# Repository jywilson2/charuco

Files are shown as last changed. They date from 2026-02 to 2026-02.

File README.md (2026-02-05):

# Parametric 3D-Printable ChArUco Calibration Target

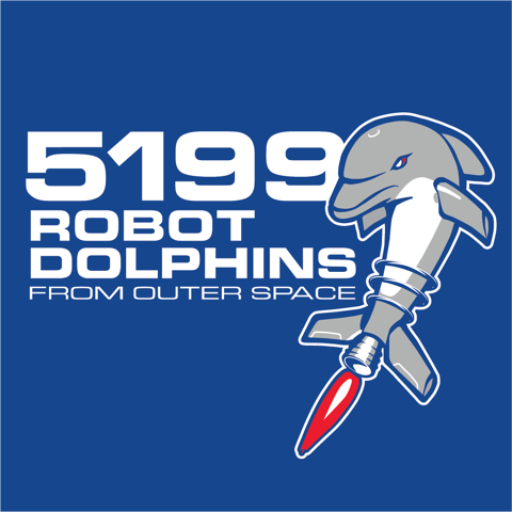
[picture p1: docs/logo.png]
Robot Dolphins from Outer Space Logo


**Developed by Robot Dolphins from Outer Space: Team 5199 & Gemini Pro**

A robust OpenSCAD toolkit for generating large-scale ChArUco calibration boards that can be split and 3D printed on standard-sized beds. This project features precision multi-material slicing support and modular assembly options, making it easy to create professional-grade computer vision calibration targets without a large-format printer.

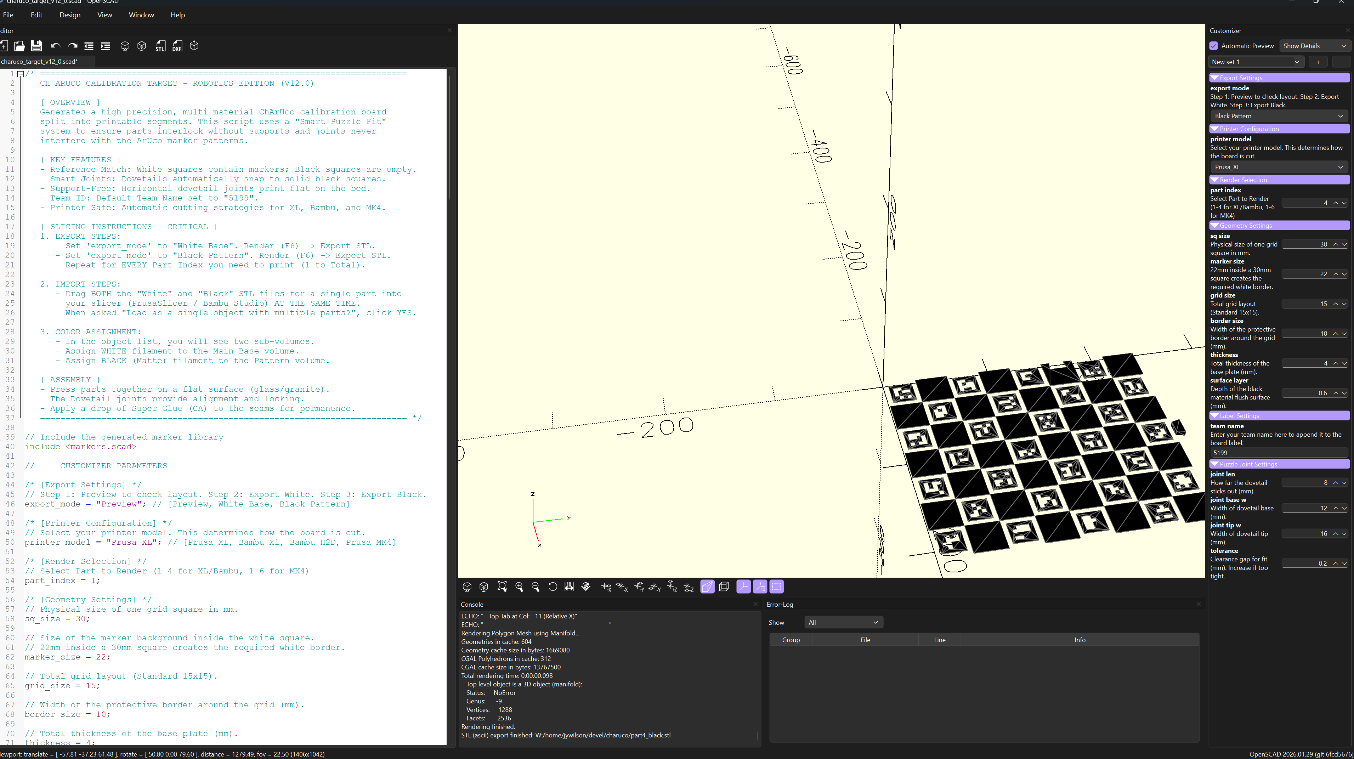
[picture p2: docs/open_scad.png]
OpenSCAD Generator Preview

*Figure 1: The parametric model rendered in OpenSCAD, showing the modular split and alignment features.*

## Pre-Generated Files

For convenience, we have provided ready-to-print files for a standard **15x15 Grid** configuration:

* **STL Models (`stl/`):** Contains exported "White Base" and "Black Pattern" files pre-configured for:
    * Prusa XL
    * Bambu Labs X1E
* **Slicer Projects (`slicer/`):** Contains pre-configured project files (with multi-material settings applied) for:
    * **Prusa Slicer** (for Prusa XL)
    * **Bambu Studio** (for Bambu Labs X1E)

## Key Features

* **Auto-Splitting:** Automatically slices large targets (e.g., 15x15 grids) into printable sections compatible with standard build volumes like the Prusa XL, Bambu X1, and Prusa MK4.
* **Modular Assembly:** Choose between two robust connection styles:
    * **Smart Dovetails:** Precision puzzle-fit with anchored geometry for a flat, glue-assembled board.
    * **Joiner Plates:** Reinforced screw-fastened connections using printed plates and standard M3/wood screws. **(⚠️ Note: This connection style is currently in development and untested.)**
* **Multi-Material Ready:** Generates separate "White Base" and "Black Pattern" STL files with anchored geometry, ensuring perfect boolean unions in slicers.
* **Robust Geometry:** Includes reinforcement bosses for screw holes and "top-open" dovetail slots to ensure easy assembly and structural integrity.
* **Python Integration:** Includes a helper script to generate standard ArUco dictionary patterns (`markers.scad`).

## Usage Summary

1.  **Generate Markers:** Run the included Python script to generate the ArUco marker library:
    ```bash
    python generate_library.py
    ```
2.  **Configure:** Open the `.scad` file in OpenSCAD and select your **Printer Model** and **Connection Type** in the Customizer.
    * *Note: Extensive usage information, advanced configuration options, and logic explanations are provided as inline comments within the SCAD source file.*
3.  **Export:** Select the **Part Index** you wish to print, then export the `White Base` and `Black Pattern` files separately.
4.  **Print:** Import both files into your slicer as a "Multi-Part Object" to preserve alignment and assign filament colors.

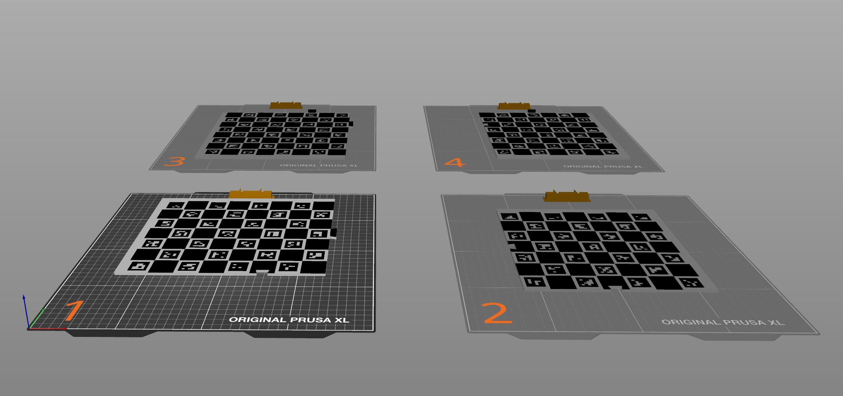
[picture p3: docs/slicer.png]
Slicer Multi-Material Setup

*Figure 2: The generated parts imported into the slicer as a single multi-material object, ready for printing.*

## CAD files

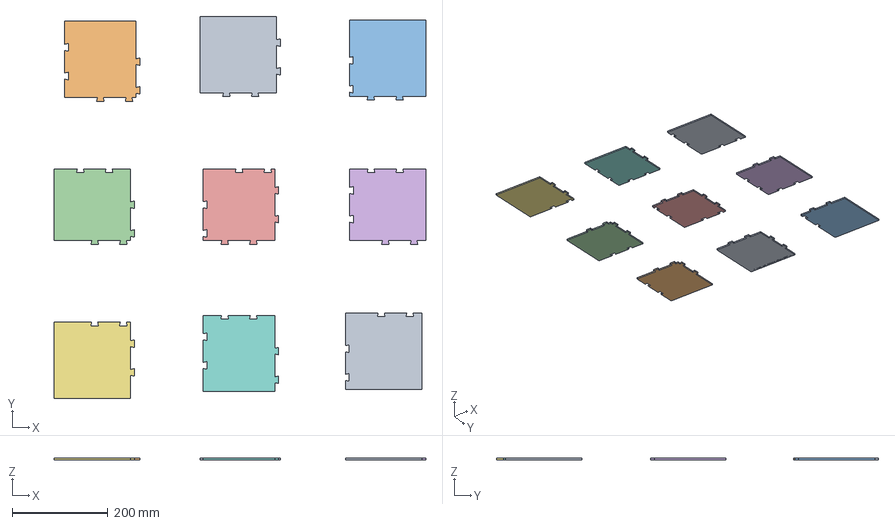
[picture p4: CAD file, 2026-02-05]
slicer/bambu_labs_x1e_15x15.3mf
778.4 x 799.9 x 4.00 mm
part_1_black_short_dove_tail
part_2_black_short_dove_tail
part_3_black_short_dove_tail
part_4_black
part_5_black
part_6_black
part_7_black
part_8_black
part_9_black

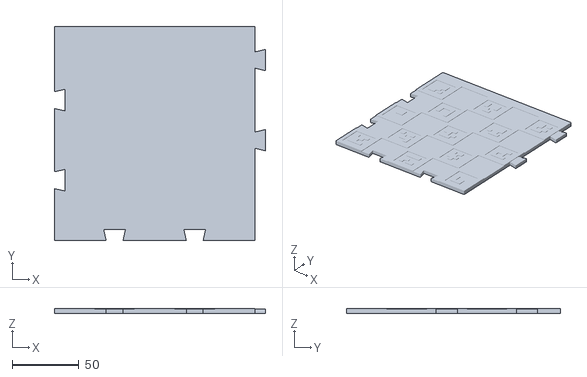
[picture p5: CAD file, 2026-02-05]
stl/bambu_labs_x1e/part_8_white.stl
158.0 x 160.0 x 4.00

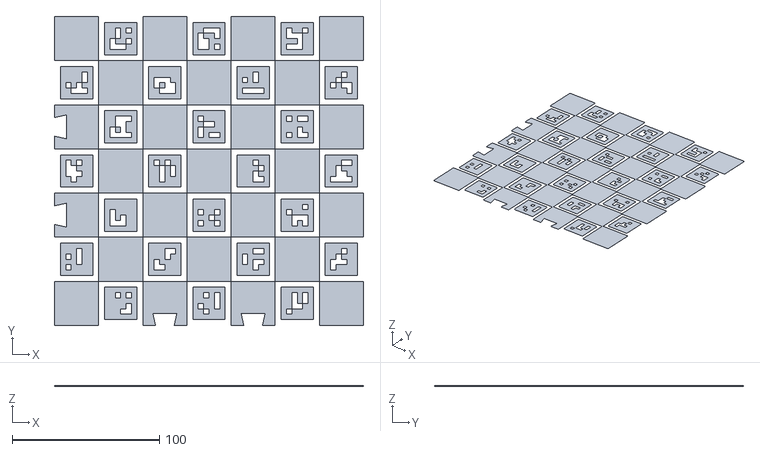
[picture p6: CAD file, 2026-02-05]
stl/prusa_xl/part2_black.stl
210.0 x 210.0 x 0.6

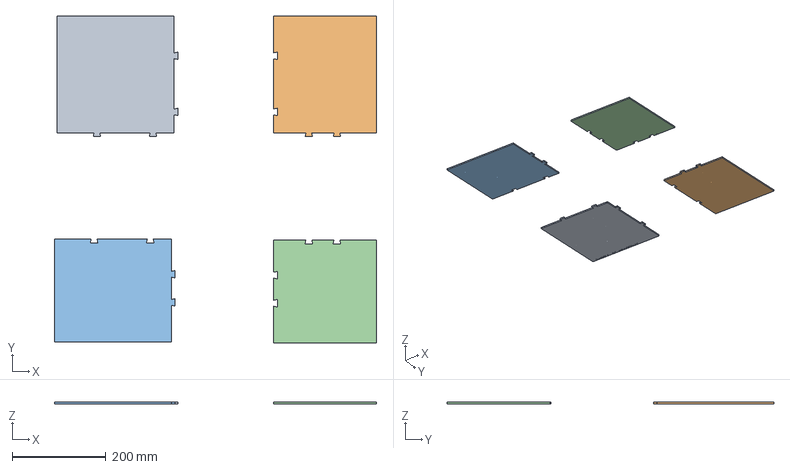
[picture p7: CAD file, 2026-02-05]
slicer/prusa_xl_15x15.3mf
689.0 x 699.1 x 4.00 mm
part3_black
part4_black
part1_black
part2_black

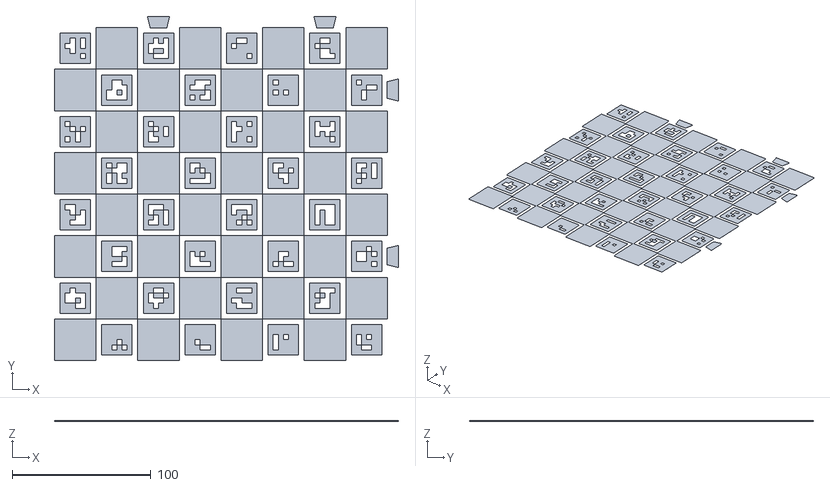
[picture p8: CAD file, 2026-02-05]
stl/prusa_xl/part3_black.stl
248.0 x 248.0 x 0.6

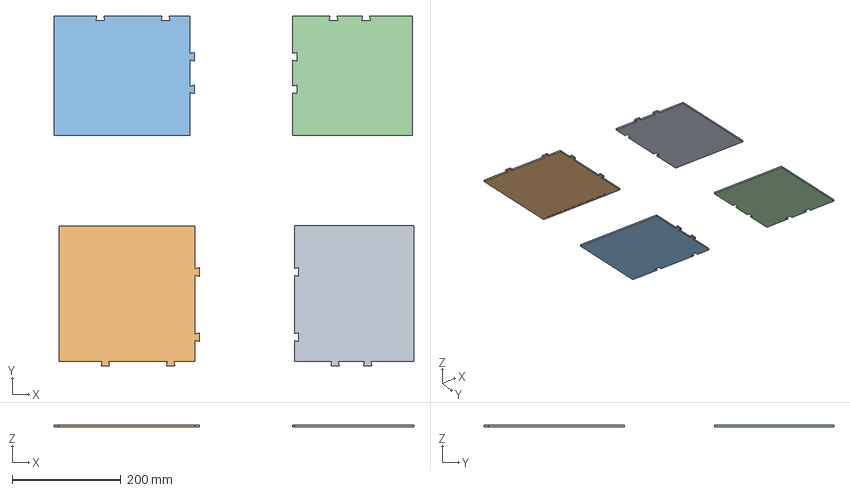
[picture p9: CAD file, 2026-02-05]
slicer/bambu_labs_h2d_15x15.3mf
661.9 x 644.0 x 4.00 mm
part4_black
part3_black
part1_black
part2_black

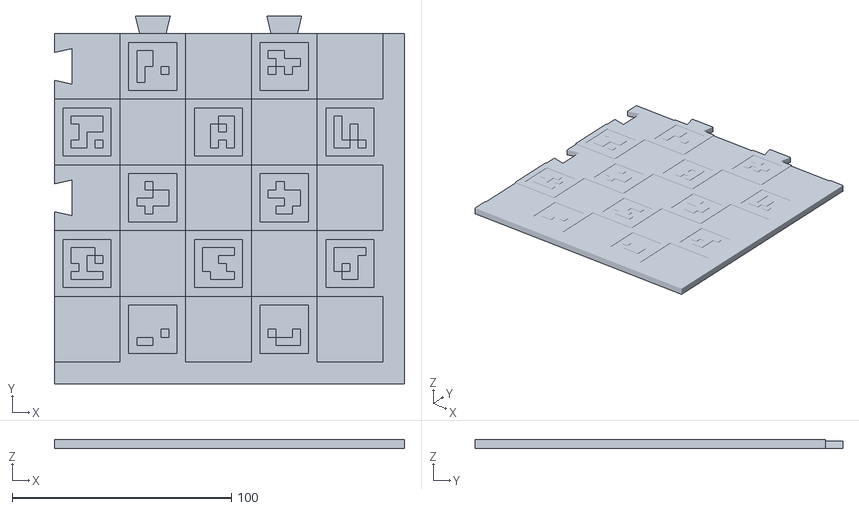
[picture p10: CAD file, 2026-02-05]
stl/bambu_labs_x1e/part_3_white.stl
160.0 x 168.0 x 4.00

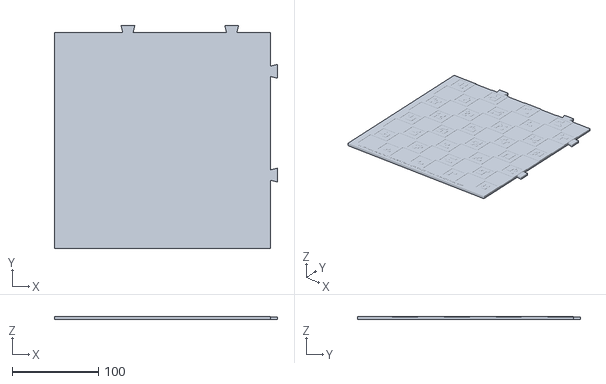
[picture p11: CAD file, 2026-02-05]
stl/prusa_xl/part3_white.stl
258.0 x 258.0 x 4.00

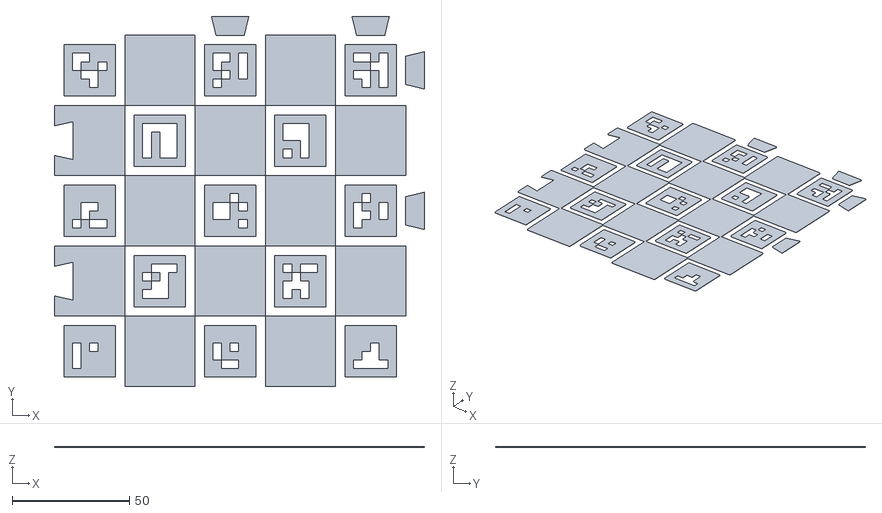
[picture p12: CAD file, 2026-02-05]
stl/bambu_labs_x1e/part_2_black.stl
158.0 x 158.0 x 0.6

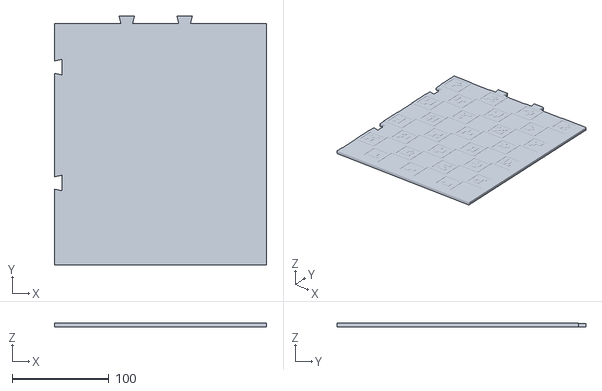
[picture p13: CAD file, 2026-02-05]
stl/prusa_xl/part4_white.stl
220.0 x 258.0 x 4.00

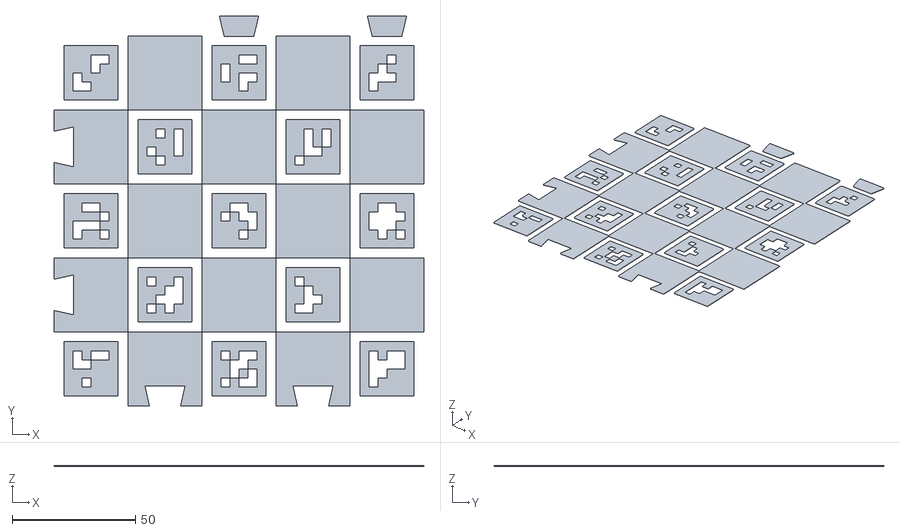
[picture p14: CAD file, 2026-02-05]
stl/bambu_labs_x1e/part_6_black.stl
150.0 x 158.0 x 0.6

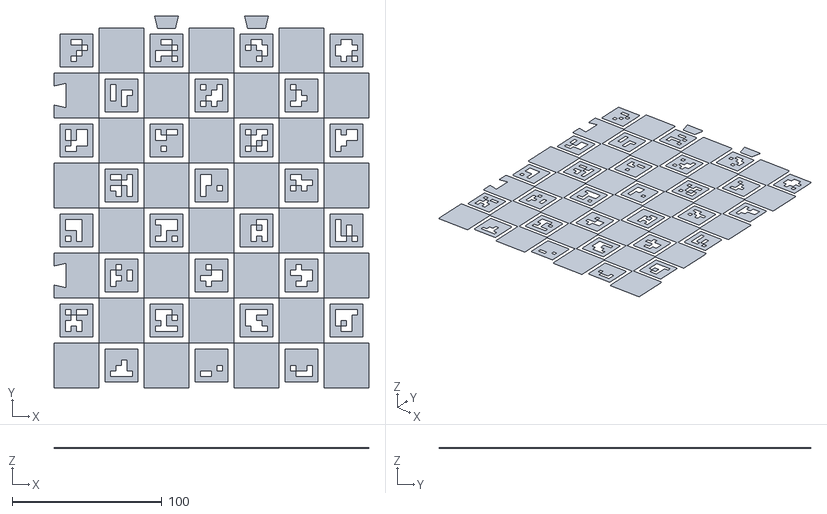
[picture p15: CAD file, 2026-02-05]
stl/prusa_xl/part4_black.stl
210.0 x 248.0 x 0.6

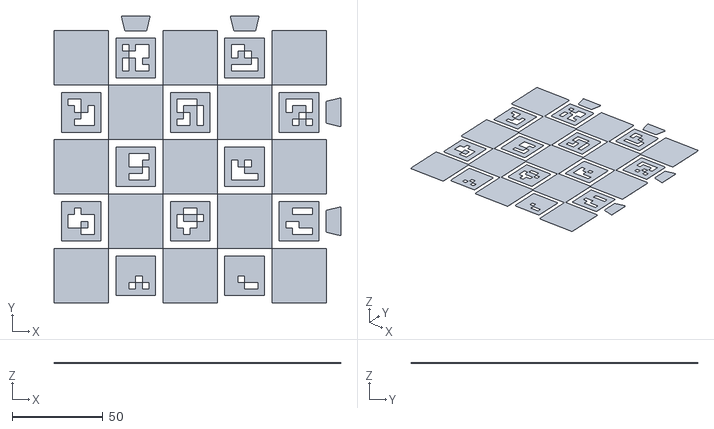
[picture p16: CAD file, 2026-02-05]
stl/bambu_labs_x1e/part_1_black.stl
158.0 x 158.0 x 0.6

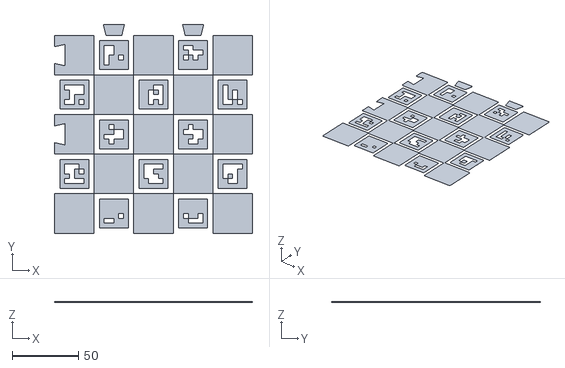
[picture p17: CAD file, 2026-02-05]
stl/bambu_labs_x1e/part_3_black.stl
150.0 x 158.0 x 0.6

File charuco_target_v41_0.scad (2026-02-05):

/* ========================================================================
   CH ARUCO CALIBRATION TARGET - SAFER CUTS EDITION (V41.0)
   
   [ CRITICAL FIX V41.0 ]
   1. UPDATED CUT STRATEGY:
      - Adjusted the 'calc_cuts' logic to account for dovetail tab overhang.
      - Previous Logic: 250mm bed -> 2-way split (Part height ~250mm).
        -> FAILED because tabs pushed it to ~258mm.
      - New Logic: 250mm bed -> 3-way split (Part height ~168mm).
      - 2-way split now requires >= 265mm print bed.
   
   2. BAMBU PRESET UPDATE:
      - Bambu X1/P1 (256mm) now defaults to the safer 3-way split [5, 10]
        to ensure comfortable clearance for brims/tabs.

   [ STANDARD FEATURES ]
   - Detailed Labels & Debug Output.
   - Anchored Dovetails & Reinforced Joiners.
   - Slicer Import Guide.

   ========================================================================
   [ SLICER IMPORT INSTRUCTIONS (Bambu / Prusa) ]
   1. EXPORT:
      - Select 'White Base' in Customizer -> Render (F6) -> Export STL.
      - Select 'Black Pattern' in Customizer -> Render (F6) -> Export STL.
      - (Repeat for every Part Index required).

   2. IMPORT:
      - Drag BOTH files into the slicer window AT THE SAME TIME.
      - A dialog will appear: "Load as single object with multiple parts?"
      - Click YES (or "Multi-Part Object").

   3. SETUP:
      - You will see ONE object in the list with two sub-parts.
      - Assign Filament 1 (White) to the Base.
      - Assign Filament 2 (Black) to the Pattern.
   ======================================================================== */

// --- CUSTOMIZER PARAMETERS (MUST BE TOP LEVEL) --------------------------

/* [General Settings] */
// Select connection style. 
connection_type = "Smart Dovetail"; // [Smart Dovetail, Joiner Plate]

/* [Export Settings] */
// Controls which part of the assembly is shown/rendered.
export_mode = "Preview"; // [Preview, White Base, Black Pattern, Joiner Plate]

/* [Printer Configuration] */
// Select "Custom" to define your own bed size.
printer_model = "Prusa_XL"; // [Prusa_XL, Bambu_X1, Bambu_H2D, Prusa_MK4, Custom]

/* [Custom Printer Settings] */
// Width of your print bed (X-axis) in mm.
custom_print_width = 0; 
// Depth of your print bed (Y-axis) in mm.
custom_print_depth = 0; 

/* [Render Selection] */
// Which split section of the board to render (starts at 1).
part_index = 1; 

/* [Geometry Settings] */
sq_size = 30;         // Grid Square size (mm)
marker_size = 22;     // Marker size (mm) - leaves 4mm black border
grid_size = 15;       // 15x15 Grid
border_size = 10;     // Border width (mm) around the chart

// Base thickness. 
// Default 4mm. Auto-increases if Joiner Plate is selected.
thickness = 4;        

// Depth of the black material flush surface (mm).
surface_layer = 0.6;  

/* [Label Settings] */
team_name = "5199"; 

/* [Dovetail Settings] */
// Only active if connection_type == "Smart Dovetail"
joint_len = 8;        
joint_base_w = 12;    
joint_tip_w = 16;     
// Clearance gap for fit. 0.1mm = Tight Snap.
tolerance = 0.1;      

/* [Joiner Plate Settings] */
// Only active if connection_type == "Joiner Plate"
plate_thickness = 3;  
plate_spacing = 50.8; 
plate_width = 20;     
plate_length = 60;    
screw_clearance_diam = 3.4; 
screw_head_diam = 7.0;
screw_pilot_diam = 2.0;

// --- LIBRARY IMPORT & VALIDATION ----------------------------------------

include <markers.scad>
assert(markers_loaded, "CRITICAL ERROR: 'markers.scad' is missing or outdated. Please run the Python generator script (V41+) to create the marker library.");

// --- 1. CALCULATIONS & LOGIC --------------------------------------------

total_board_w = (grid_size * sq_size) + (2 * border_size);
total_board_h = (grid_size * sq_size) + (2 * border_size);

effective_thickness = (connection_type == "Joiner Plate" && thickness <= 4) ? 9 : thickness;

label_base = str(grid_size, "x", grid_size, " Grid | ", sq_size, "mm Sq / ", marker_size, "mm Mrk | DICT_4X4_250 | ID Order: TL to BR");
full_label_text = (team_name == "") ? label_base : str(label_base, " | Team: ", team_name);

// --- CUT STRATEGY LOGIC ---
// [UPDATE V41] Thresholds bumped to account for ~8mm tab overhangs + brim.
// 265mm+ Bed -> Allows 8-square split (250mm body + tabs).
// <265mm Bed -> Forces 5-square split (160mm body + tabs).
function calc_cuts(dim) = (dim >= 265) ? [8] : [5, 10]; 

cut_config_xl    = [[8], [8]];          // 360mm bed: [8] is safe.
cut_config_bambu = [[5, 10], [5, 10]];  // 256mm bed: [5,10] is required.
cut_config_mk4   = [[5, 10], [5, 10]];  // 250mm bed: [5,10] is required.
cut_config_custom = (printer_model == "Custom") ? [calc_cuts(custom_print_width), calc_cuts(custom_print_depth)] : [[0],[0]]; 

config = (printer_model == "Prusa_MK4") ? cut_config_mk4 : 
         (printer_model == "Prusa_XL")  ? cut_config_xl :
         (printer_model == "Bambu_X1" || printer_model == "Bambu_H2D") ? cut_config_bambu :
         cut_config_custom;

cuts_x = config[0];
cuts_y = config[1];

function get_ranges(cx, cy, gs) = [
    for (y_i = [0 : len(cy)]) 
        for (x_i = [0 : len(cx)]) 
            [
                (x_i==0 ? 0 : cx[x_i-1]),
                (x_i==len(cx) ? gs : cx[x_i]),
                (y_i==0 ? 0 : cy[y_i-1]),
                (y_i==len(cy) ? gs : cy[y_i])
            ]
];

raw_parts = get_ranges(cuts_x, cuts_y, grid_size);
total_parts = len(raw_parts);

// --- 2. ERROR CHECKING --------------------------------------------------

is_custom_invalid = (printer_model == "Custom") && (custom_print_width <= 0 || custom_print_depth <= 0);
assert(!is_custom_invalid, "CRITICAL ERROR: Printer Model 'Custom' selected, but dimensions are 0.");
assert(!(connection_type == "Joiner Plate" && effective_thickness < 6), "WARNING: Joiner Plate mode requires thickness >= 6mm.");
assert(part_index > 0 && part_index <= total_parts, str("CRITICAL ERROR: Part Index ", part_index, " is out of range. Total Plates: ", total_parts));

// --- 3. CONSOLE DEBUGGING -----------------------------------------------
echo("=================================================");
echo("   CHARUCO GENERATOR - DEBUG OUTPUT (V41.0)      ");
echo("=================================================");
echo(str("[CONFIG] Connection  : ", connection_type));
echo(str("[CONFIG] Board Thick : ", effective_thickness, " mm"));
echo(str("[INFO]   Total Plates Required : ", total_parts));
echo(str("[INFO]   Cut Strategy X        : ", cuts_x));
echo(str("[INFO]   Cut Strategy Y        : ", cuts_y));

// Layout Indication
echo("-------------------------------------------------");
echo("[INFO] GRID LAYOUT MAPPING:");
echo("   - Origin (Row 0, Col 0): TOP-LEFT Corner.");
echo("   - Square (0,0): Solid Black (Even Sum).");
echo("   - First Marker (ID 0): Located at Row 0, Col 1.");
echo("   - Index Order: Left-to-Right, then Top-to-Bottom.");

// Label Content Verification
echo("-------------------------------------------------");
echo(str("[INFO]   Label Text            : ", full_label_text));

// Slicer Instructions
echo("-------------------------------------------------");
echo("[GUIDE] SLICER IMPORT INSTRUCTIONS:");
echo("   1. Export 'White Base' & 'Black Pattern' STLs.");
echo("   2. Drag BOTH files into Slicer AT THE SAME TIME.");
echo("   3. Answer YES to 'Load as single object with multiple parts?'.");
echo("   4. Assign Colors: Part 1 = White, Part 2 = Black.");
echo("-------------------------------------------------");

if (part_index <= total_parts) {
    echo(str("[INFO]   Rendering Part Index  : ", part_index));
}
echo("=================================================");

// --- 4. PART MAPPING ----------------------------------------------------

map_idx = (total_parts == 4) ? [2, 3, 0, 1] : [ for (i = [0 : total_parts-1]) i ];
valid_index = (part_index > 0 && part_index <= total_parts) ? part_index : 1;
current_part = raw_parts[map_idx[valid_index - 1]];

p_xs = current_part[0]; p_xe = current_part[1];
p_ys = current_part[2]; p_ye = current_part[3];

is_left_edge   = (p_xs == 0);
is_right_edge  = (p_xe == grid_size);
is_bottom_edge = (p_ys == 0);
is_top_edge    = (p_ye == grid_size);

has_seam_x = (!is_right_edge); 
has_seam_y = (!is_top_edge);   
has_slot_x = (!is_left_edge);  
has_slot_y = (!is_bottom_edge);

// --- 5. SMART INDEXING --------------------------------------------------
function get_dual_smart_indices(fixed_coord, range_start, range_end) = 
    let (
        len = range_end - range_start,
        t1 = range_start + floor(len / 3),
        t2 = range_start + floor(2 * len / 3),
        idx1 = ((fixed_coord + t1) % 2 == 0) ? t1 : t1 + 1,
        idx2 = ((fixed_coord + t2) % 2 == 0) ? t2 : t2 + 1
    )
    [ 
      (idx1 < range_end) ? idx1 : range_start, 
      (idx2 < range_end && idx2 != idx1) ? idx2 : (idx1 + 2 < range_end ? idx1+2 : range_start)
    ];
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

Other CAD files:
stl/bambu_labs_x1e/part_6_white.stl
stl/prusa_xl/part1_white.stl
stl/prusa_xl/part1_black.stl
stl/bambu_labs_x1e/part_4_white.stl
stl/bambu_labs_x1e/part_1_white.stl
stl/bambu_labs_x1e/part_2_white.stl
stl/bambu_labs_x1e/part_4_black.stl
stl/bambu_labs_x1e/part_5_black.stl
stl/bambu_labs_x1e/part_5_white.stl
stl/bambu_labs_x1e/part_7_black.stl
stl/bambu_labs_x1e/part_7_white.stl
stl/bambu_labs_x1e/part_8_black.stl
stl/bambu_labs_x1e/part_9_black.stl
stl/bambu_labs_x1e/part_9_white.stl
stl/prusa_xl/part2_white.stl

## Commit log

2026-02-05 Initial commit.
    [bambu_labs_h2d_15x15.3mf, bambu_labs_x1e_15x15.3mf, charuco_target_v41_0.scad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]
2026-02-05 Added note to indicated that the Joiner Plate connectors are untested.
2026-02-05 Added additional plates in the X1E slicer project file.
    [bambu_labs_x1e_15x15.3mf]
